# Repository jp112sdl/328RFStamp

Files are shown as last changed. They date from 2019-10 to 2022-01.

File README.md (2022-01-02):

# 328RFStamp

https://user-images.githubusercontent.com/18190139/147872786-335e677a-a8d6-4a60-accb-12a7c5812dc8.mp4

universelle Trägerplatine für ein CC1101 Funkmodul und einen ATmega328P in kleinstmöglicher Abmessung.<br/>
- ISP Anschluss erfolgt über die Pins des CC1101.
- FTDI Pins sind 2mm-RM! 

#### Parts
| Anzahl | Ref | Typ | Bezeichnung |
|----|----|----|----|
1 | U1 | AVR | [ATMega 328P-AU](https://www.reichelt.de/mcu-atmega-avr-risc-32-kb-20-mhz-tqfp-32-atmega-328p-au-p119684.html)
1 | IC1 | RF-Module | [CC1101](https://de.aliexpress.com/item/32852540940.html)
1 | R1 | Widerstand 10k | [RND 0805 10k](https://www.reichelt.de/smd-widerstand-0805-10-kohm-125-mw-1-rnd-0805-1-10k-p183251.html)
1 | R2 | Widerstand 330 | [RND 0805 330](https://www.reichelt.de/smd-widerstand-0805-330-ohm-125-mw-1-rnd-0805-1-330-p183184.html)
3 | C1, C2, C4 |Kondensator 100n |[X7R-G0805 100N](https://www.reichelt.de/smd-vielschicht-keramikkondensator-100n-10-x7r-g0805-100n-p31879.html)
1 | C3 |Kondensator Tantal 10µ |[T491B 10U 16](https://www.reichelt.de/smd-tantal-10-f-16v-125-c-t491a-10u-16-p206441.html)

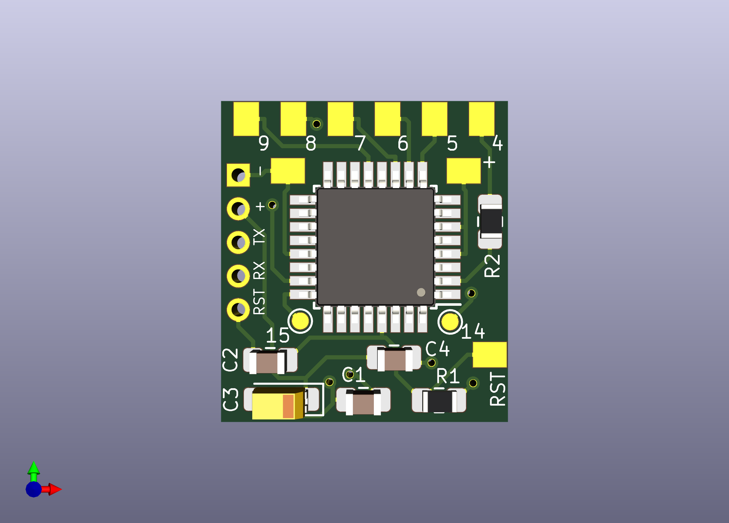
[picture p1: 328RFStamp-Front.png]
front


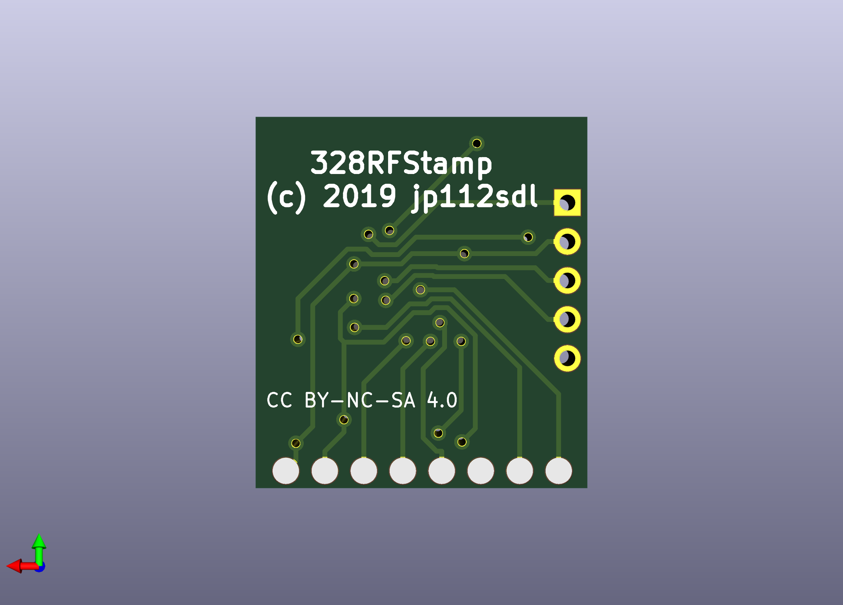
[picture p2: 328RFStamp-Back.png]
back


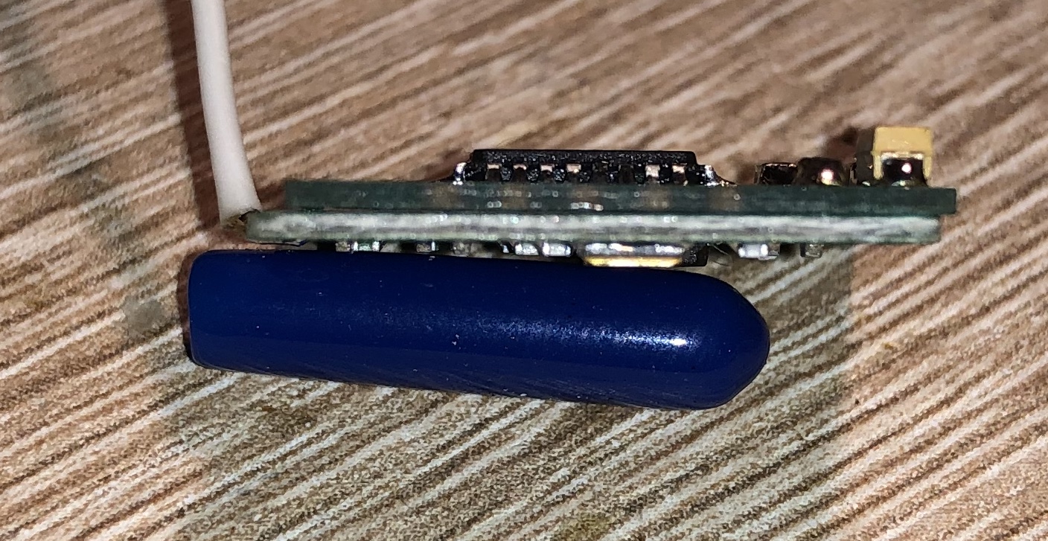
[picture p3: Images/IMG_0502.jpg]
p1


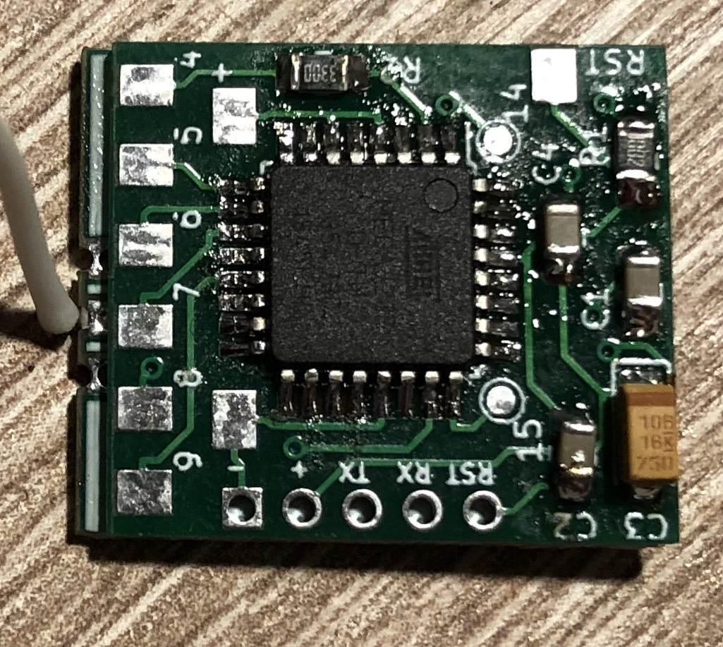
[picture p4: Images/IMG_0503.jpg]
p2


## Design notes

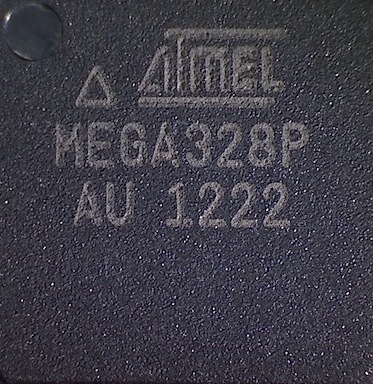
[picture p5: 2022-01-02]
blender/328p.jpg

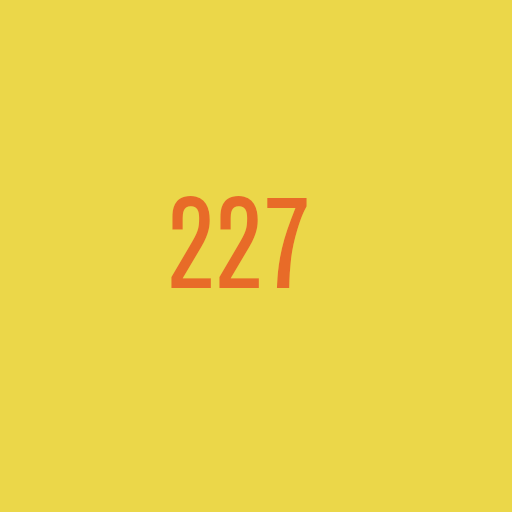
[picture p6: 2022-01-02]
blender/C227.png

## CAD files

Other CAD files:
blender/328RFSTamp.blend

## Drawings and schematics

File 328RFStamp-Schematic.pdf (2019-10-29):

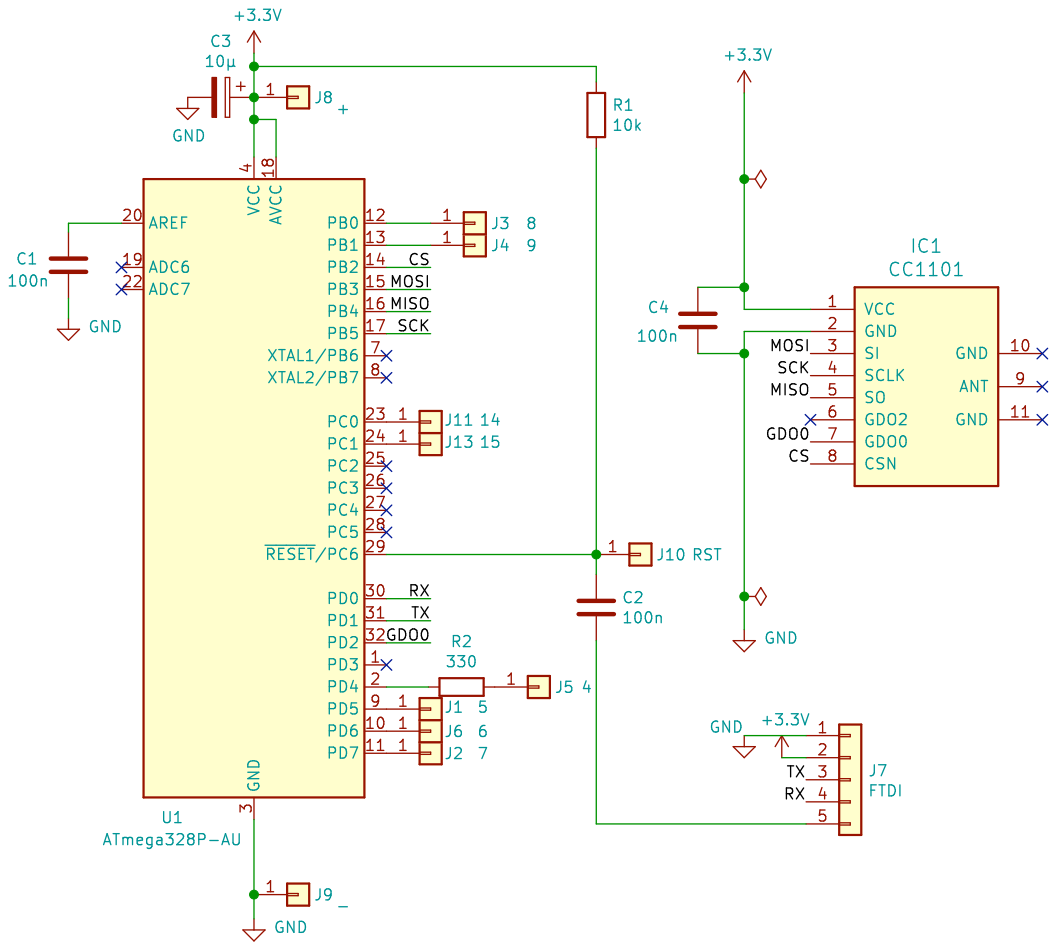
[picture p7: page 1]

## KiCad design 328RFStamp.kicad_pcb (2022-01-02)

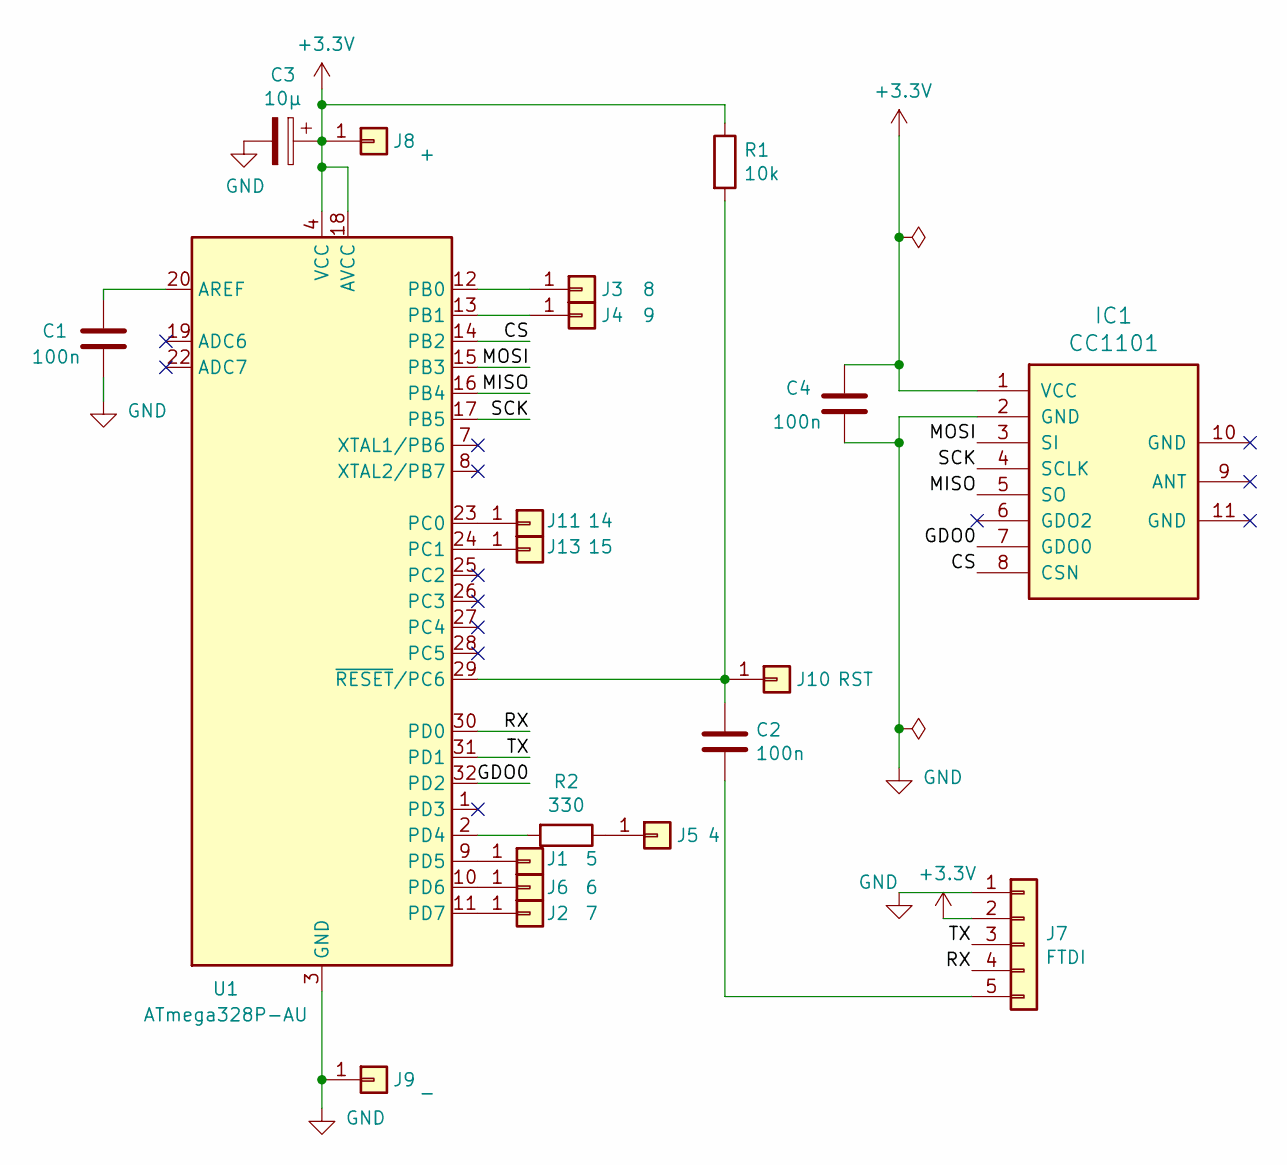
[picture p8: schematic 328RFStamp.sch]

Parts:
C1, C2, C4: 100n; C_0805_2012Metric_Pad1.15x1.40mm_HandSolder
C3: 10µ; CP_EIA-3216-18_Kemet-A_Pad1.58x1.35mm_HandSolder
IC1: CC1101; PinHeader_1x08_P2.00mm_Vertical
J1: 5; TestPoint_Pad_D1.5mm
J2: 7; TestPoint_Pad_D1.5mm
J3: 8; TestPoint_Pad_D1.5mm
J4: 9; TestPoint_Pad_D1.5mm
J5: 4; TestPoint_Pad_D1.5mm
J6: 6; TestPoint_Pad_D1.5mm
J7: FTDI; PinHeader_1x05_P2.00mm_Vertical
J8: +; TestPoint_Pad_D1.5mm
J9: -; TestPoint_Pad_D1.5mm
J10: RST; TestPoint_Pad_D1.5mm
J11: 14; TestPoint_Pad_D1.0mm
J13: 15; TestPoint_Pad_D1.0mm
R1: 10k; R_0805_2012Metric_Pad1.15x1.40mm_HandSolder
R2: 330; R_0805_2012Metric_Pad1.15x1.40mm_HandSolder
U1: ATmega328P-AU; TQFP-32_7x7mm_P0.8mm

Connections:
+3V3: C3.1, C4.1, IC1.1 (VCC), J7.2, J8.1, R1.1, U1.4 (VCC), U1.6 (VCC), U1.18 (AVCC)
/CS: IC1.8 (CSN), U1.14 (PB2)
/GDO0: IC1.7 (GDO0), U1.32 (PD2)
/MISO: IC1.5 (SO), U1.16 (PB4)
/MOSI: IC1.3 (SI), U1.15 (PB3)
/RX: J7.4, U1.30 (PD0)
/SCK: IC1.4 (SCLK), U1.17 (PB5)
/TX: J7.3, U1.31 (PD1)
GND: C1.2, C3.2, C4.2, IC1.2 (GND), J7.1, J9.1, U1.3 (GND), U1.5 (GND), U1.21 (GND)
unnamed: C1.1, U1.20 (AREF)
unnamed: C2.1, J10.1, R1.2, U1.29 (~RESET~/PC6)
unnamed: C2.2, J7.5
unnamed: J1.1, U1.9 (PD5)
unnamed: J2.1, U1.11 (PD7)
unnamed: J3.1, U1.12 (PB0)
unnamed: J4.1, U1.13 (PB1)
unnamed: J5.1, R2.1
unnamed: J6.1, U1.10 (PD6)
unnamed: J11.1, U1.23 (PC0)
unnamed: J13.1, U1.24 (PC1)
unnamed: R2.2, U1.2 (PD4)

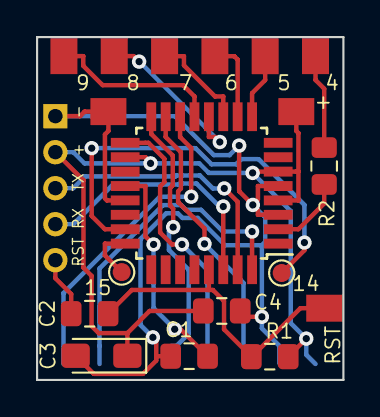
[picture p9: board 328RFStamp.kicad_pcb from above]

Board: 2 copper layers, 17.0 x 19.0 mm, 20 parts (1 on the bottom side), 21 nets.

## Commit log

2019-10-29 corrected value for C3
    [328RFStamp.sch]
2022-01-02 update to KiCad 6
    [328RFStamp.kicad_pcb]
2022-01-02 add blender project
    [328RFSTamp.blend]
2022-01-12 update blender
    [328RFSTamp.blend]

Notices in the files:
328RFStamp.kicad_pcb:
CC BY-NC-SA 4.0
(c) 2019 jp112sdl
